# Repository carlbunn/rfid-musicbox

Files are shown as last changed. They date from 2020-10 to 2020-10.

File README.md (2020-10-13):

# rfid-musicbox

Create an easy way for your kids (or you!) to play music through your Sonos speakers by combining the excitement of RFID, ESP8266, Spotify & Sonos.

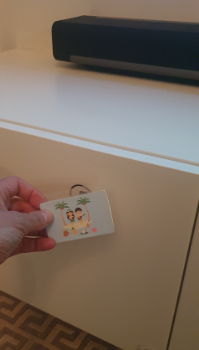
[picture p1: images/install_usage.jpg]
rfid-musicbox-install-usage
 

This project was built to predominantly allow my kids to play music, using simple RFID cards tapped against a reader to allow them to play the songs that they love without me being around.

1. [Repository File Structure](#repository-file-structure)
2. [Requirements](#requirements)
3. [ELectronics](#electronics)
4. [Software Build & Installation](#software-build--installation)
5. [Setup](#setup)
6. [Physical Installation](#physcial-installation)
7. [Usage](#usage)
8. [RFID Cards](#rfid-cards)
9. [References](#references)

## Repository File Structure
- /Fritzing - sketch of the wiring diagram
- /html - reference html of the pages served from the musicbox webserver
- /images - supporting images for documentation & build
- /src - source files for the project

## Requirements
This project should be extendable to additional music services, but was built to support playing Spotify songs through a network connected Sonos speaker. So at a minimum you will need:
1. Spotify Premium subscription
2. At least one Sonos speaker, connected to the same wifi network
3. 1 x NodeMCU ESP8266 board - I suggest the NodeMCU v3 Compatible ESP8266 CH340 Board, and make sure you check the version
4. 1 x MFRC-522 RFID reader board - you can sometimes pick up a kit for this that includes cables, and an RFID card
5. 7 x jumper wires to connect the MFRC-522 to the NodeMCU board
6. RFID cards - as many as you need, but at least one for testing. I bought a pack of 20 to start
7. 1 x Micro USB cable, and 1 USB Power Supply - I don't think the power requirements of the NodeMCU are that great, but your smartphone power supply will easily do

There are a few additional items I purchased for my particular set-up:
1. Something to put the assembled electronics in to. I used a simple plastic project box from a local electronics supplier.
2. A Micro USB 5Pin Male to Female w/Screw Hole Panel. I used this to put a female USB plug on the outside of the project box, and make it easier to unplug/move as needed.

## Electronics
To start with, you'll need to connect the electronics as shown below, or detailed in the [Fritzing wiring diagram](Fritzing/RFID-Musicbox.fzz).

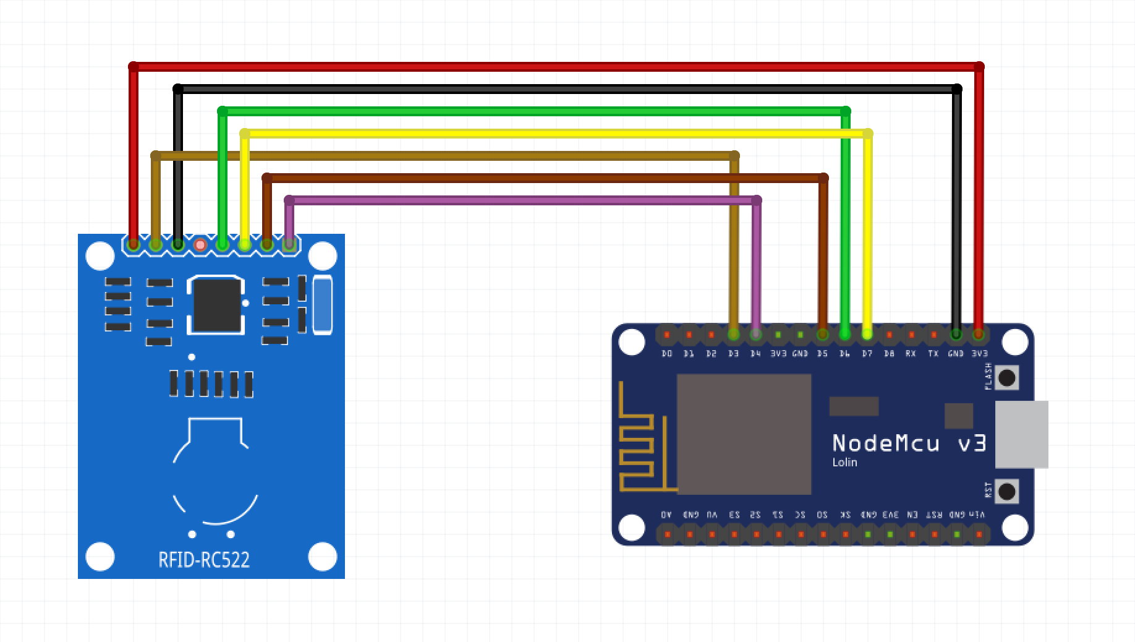
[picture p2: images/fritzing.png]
rfid-musicbox-Fritzing


Once connected, connect the Micro USB cable and power supply to the NodeMCU board.

## Software Build & Installation
The source code for this project was originally written uisng VS Code, and compiled using the [Platform IO](https://platformio.org/) plugin. If you'd prefer to use the Arduino IDE, a quick Google search should show you how to (relatively) easily adapt the source files to work as an .ino format.

*Note: Before you start the below steps, make sure your NodeMCU/ESP8266 board is connected to and powered by the USB port of your computer, not to the USB Power Supply.*

If you have already have VS Code installed:
1. Install [Platform IO IDE for VS Code](https://platformio.org/install/ide?install=vscode)
2. Add a new workspace using the **rfid-musicbox** folder
3. Build and upload the firmware using the IDE [this guide](https://docs.platformio.org/en/latest/integration/ide/vscode.html#ide-vscode) is helpful to get started

If you just want to install Platform IO to run on the command line:
1. Install [Platform IO Core](https://platformio.org/install/cli)
2. Open a command line prompt
3. Change to the **rfid-musicbox** folder
4. Run `platformio run --target upload`

By this point, you should have compiled the firmware and uploaded it to the NodeMCU.

## Setup
1. After the firmware is uploaded and installed, look for a new wifi hotspot named `musicbox_setup` using your phone or computer
2. Connect your device to the wifi hotspot, using the password `musicbox_setup`
3. The hotspot should automatically connect you using a captive portal style web page, otherwise just point your browser to the IP `http://192.168.4.1/`
4. Enter the details of/select your home Wifi network (along with network password) in the provided form, then click save
5. The rfid-musicbox should now try to connect to your home Wifi network
6. After a few seconds (/minutes) try to connect to `http://musicbox.local/` using your browser

*Note: If you use an Android phone to connect to the ESP8266, you might find you have trouble connecting due to inconsistent support for mDNS in Android phones. As a workaround, try connecting using the IP address of the device which you can find using your Router or using an app like [Fing](https://www.fing.com/products/fing-app)*

## Physcial Installation
I needed something that ensured the project box and electronics were all kept out of reach of my kids, and that they only had access to scan cards against a surface. Thankfully I had some Ikea cabinets installed under my TV that also happen to be directly underneath my loungeroom Sonos PLAYBAR.

The Ikea cabinets are standard [Besta cabinets](https://www.ikea.com/au/en/p/besta-tv-bench-with-doors-white-lappviken-white-s19299137/) with doors that are approximately 17mm thick, and the RFID signal has no problem passing through them.

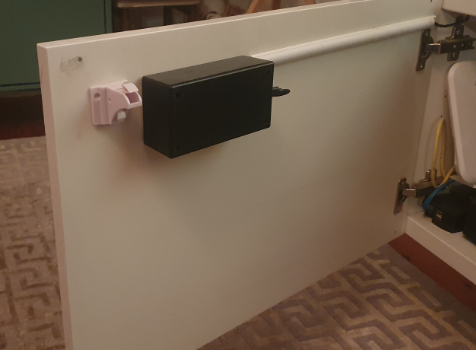
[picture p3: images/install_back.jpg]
rfid-musicbox-install-back
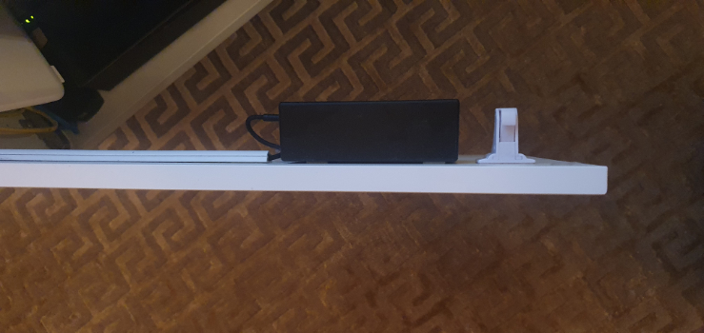
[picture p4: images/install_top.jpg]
rfid-musicbox-install-top
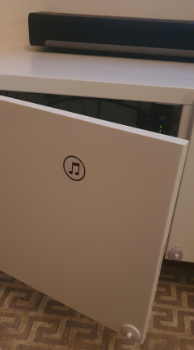
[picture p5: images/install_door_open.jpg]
rfid-musicbox-install-door-open
  

You can see from the images that I ended up running some simple trunking across the back of the door to house the USB power cable, and this runs to an extension within the cabinet.

I also printed out and stuck to the door a small music icon, just as a visual reference for the kids to know where to tap the RFID card. The icon was simply printed on A4, and stuck to the cabinet using [clear film](https://www.officeworks.com.au/shop/officeworks/p/studymate-self-adhesive-book-cover-roll-450mm-x-5m-clear-sm5450) (the kind you use to put over books to protect them)

## Usage
To start with, you'll need to assign a song to an RFID card. The URI information to access the song is stored on the RFID card, so you should be able to use one card to control multiple NodeMCUs with the same song.

To programme a card with a song:
1. Point your web browser to `http://musicbox.local/` (see the Note in [set-up](#setup) if you can't connect to this URL from your device)

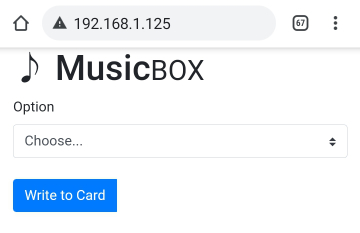
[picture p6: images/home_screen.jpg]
rfid-musicbox-home-screen


2. Select `Play Item` from the `Option` menu

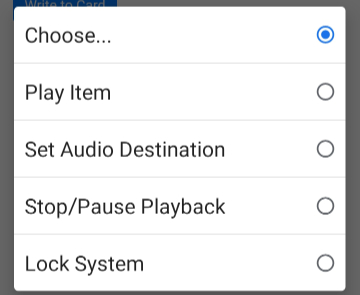
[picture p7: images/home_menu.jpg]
rfid-musicbox-home-menu


3. Click on the `Open Spotify Web Player` link to open a new browser page to the Spotify web player

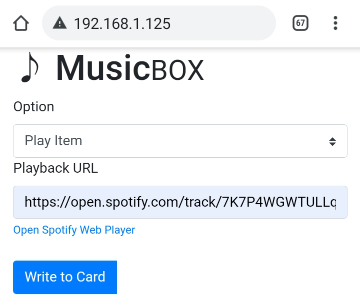
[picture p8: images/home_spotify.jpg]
rfid-musicbox-home-spotify


4. Search for the song you wish to write to the card in the Spotify web player
5. Hover over the selected song and click on the 3 dots rfid-musicbox-dots towards the right to open the menu
6. Select `Copy Song Link` to copy the link to the song to your clipboard

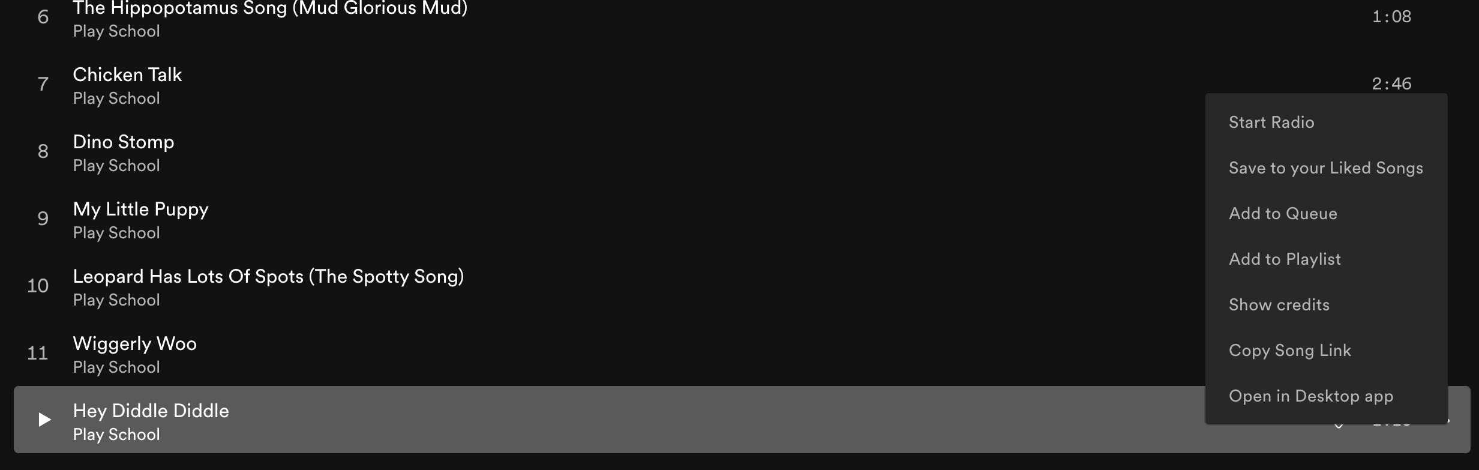
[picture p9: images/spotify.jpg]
rfid-musicbox-spotify


7. Close the window/navigate back to the browser page for the NodeMCU
8. Copy the song URL in to the `Playback URL` box
9. Click on `Write to Card`. You have 10 seconds to hold the RFID card you want to programme against the RFID reader/writer.

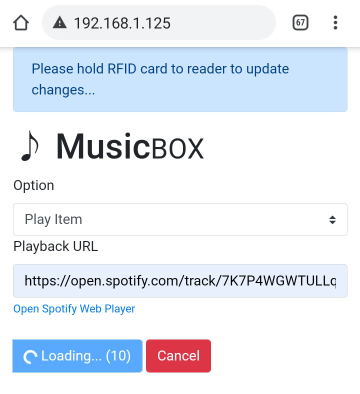
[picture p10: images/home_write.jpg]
rfid-musicbox-home-write


## RFID Cards
You can 'programme' an RFID card to start 1 of 4 different actions:
1. Play Item - play a song through the currently selected speaker
2. Set Audio Destination - change which Sonos speaker plays the next song
3. Stop/Pause Playback - pause/stop playback through the currently selected speaker
4. Lock System - lock and unlock the system from reading RFID cards (except a Lock card)
   - Note: 'locking' the system doesn't persist over reboots, so if the power is lost then the device will be unlocked again

All of this is done through the web interface.

To make the cards be easy to use for the kids, I used some colourful images sourced online that closely reflect the song title. These were printed out (using a standard printer), cut out, stuck to the cards using a spot of glue, and finally laminated to make them more durable. They work fantastically, and after a year are still looking like new.

I can't share the images I used, but I've included a [template file](images/card_template.afphoto) that you can use to size your images correctly for printing out.

## References
I used a lot of different references to build this project, and am thankful to a massive amount of online resources. Key resources I found extremely helpful included:
- https://lastminuteengineers.com/how-rfid-works-rc522-arduino-tutorial/ - a great reference on how RFID works, and how to combine it with an Arduino or equivalent device
- https://github.com/TheNitek/RfidShelf - awesome project, working to build an RFID mp3 player in to a shelf, which might be a good solution if you don't use Sonos or Spotify

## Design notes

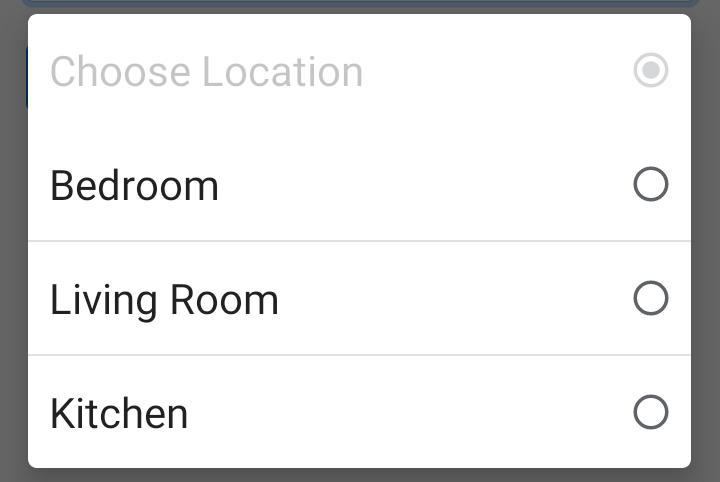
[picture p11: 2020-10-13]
images/home_location.jpg

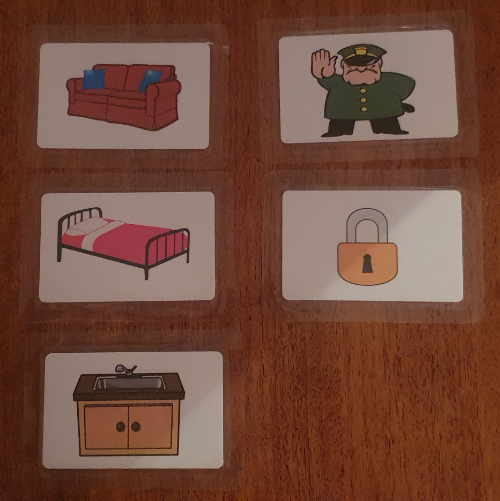
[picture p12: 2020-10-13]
images/cards_control.jpg

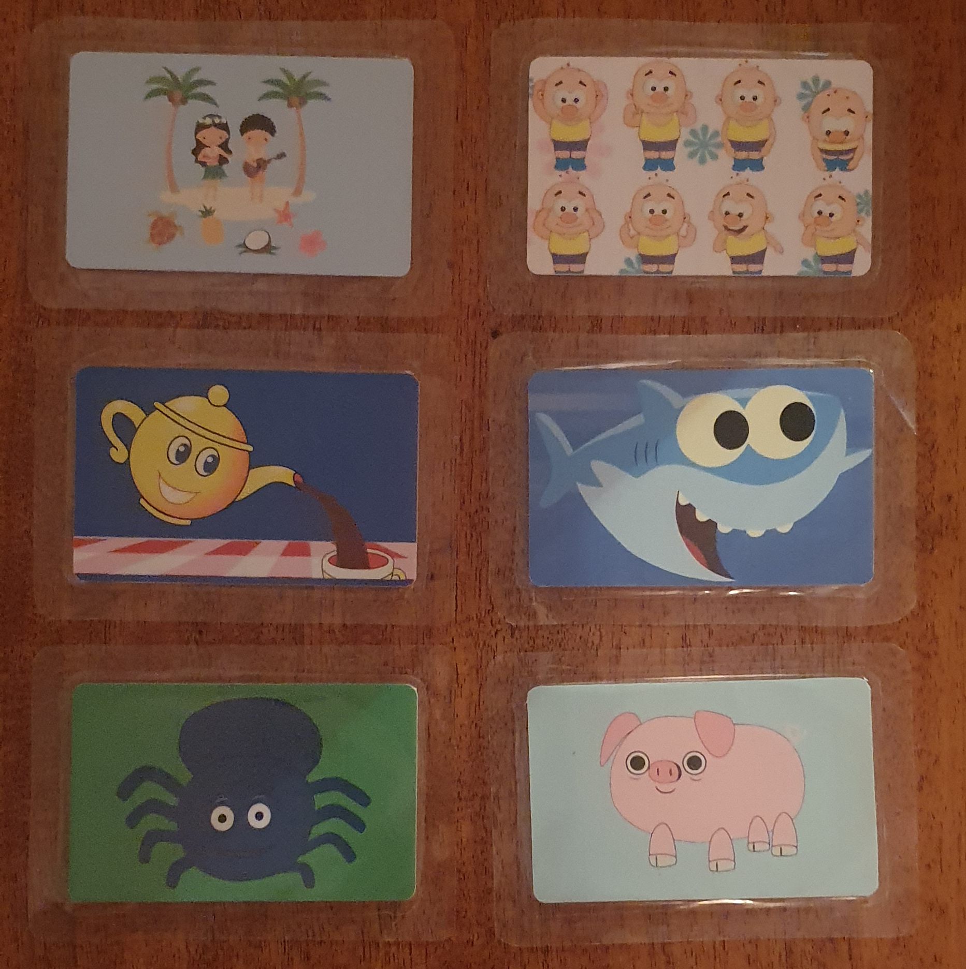
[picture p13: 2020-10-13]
images/cards_songs.jpg

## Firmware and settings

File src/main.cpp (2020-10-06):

#include <Arduino.h>
#include <WiFiManager.h>
#include "Config.h"
#include "Sonos.h"
#include "Rfid.h"
#include "WebServer.h"

#define MAIN_START_RFID
#define MAIN_START_SONOS
#define MAIN_START_WEB

// Defining instances to be used later
// in the setup and loop
Sonos g_sonos;
WiFiManager g_wifi_manager;
Rfid g_rfid_instance;
WebServer g_web_server;

// Using this as a bit of a hack to start/stop
// processing RFID requests
bool g_lock;

// We only support spotify at the moment, so
// we don't really store this value anywhere
// except here
const char* g_service_name = "spotify";
uint16_t g_service_id = 0;

// Currently using this to manage ongoing discovery
// of the sonos clients in the loop
unsigned long target_time = 0L;
const unsigned long DISCOVER_PERIOD = 2*60*1000UL; // 2 minutes

/**
 * Check and save any change of location
 *
 * Checks if the audio destination for playing has
 * changed, and if so it attempts to save that config
 * in the defined storage environment.
 */
void checkLocationChange()
{
    const SonosClient* client = g_sonos.getActiveClient();

    if (strcmp(CONFIG.stored_config.last_sonos_serial, client->serial_num) != 0)
    {
        memset(CONFIG.stored_config.last_sonos_serial, 0, sizeof(CONFIG.stored_config.last_sonos_serial));
        memcpy(CONFIG.stored_config.last_sonos_serial, client->serial_num, sizeof(client->serial_num));
        
        Serial.print(F("main::checkLocationChange saving Location change: "));Serial.println(CONFIG.stored_config.last_sonos_serial);

        // Write out the config to save it
        CONFIG.writeConfig();

        Serial.print(F("main::checkLocationChange Location change saved: "));Serial.println(CONFIG.stored_config.last_sonos_serial);
    }
}

/**
 * Process the callback from any RFID tag that's read
 *
 * Main callback passed to the RFID class, which in
 * turn processes the data provided that's read.
 */
void readRFIDCallback(const uint8_t* t_card_uid, const uint8_t* t_read_buffer, uint8_t t_buffer_size)
{
    // Just make sure that we have something to process
    if (!t_read_buffer)
    {
        Serial.print(F("main::readRFIDCallback no valid buffer provided/found"));
        return;
    }

    Serial.print(F("main::readRFIDCallback called ["));Serial.print((char*)t_read_buffer);Serial.println(F("]"));

    // Split the buffer up to the first space character
    // Commands should be one of:
    //   <COMMAND>
    //   <COMMAND> <ARGUMENT>
    char* command = strtok((char*)t_read_buffer, " ");
    
    if ((!g_lock) && strcmp(command, "PLAY") == 0)
    {
        // PLAY: expect next argument is a uri
        char* argument = strtok(NULL, " ");
        if (argument != NULL)
        {
            Serial.print(F("main::readRFIDCallback PLAY command ["));Serial.print(argument);Serial.println(F("]"));
            g_sonos.queueUri(g_service_id, argument);
            g_sonos.play();
        }
    }
    else if ((!g_lock) && strcmp(command, "LOCATION") == 0)
    {
        // LOCATION: expect next number is a Sonos Serial# for a location
        char* argument = strtok(NULL, " ");
        if (argument != NULL)
        {
            Serial.print(F("main::readRFIDCallback LOCATION command ["));Serial.print(argument);Serial.println(F("]"));
            g_sonos.setActiveClient(argument);

            // Check & save any change in the active client
            checkLocationChange();
        }
    }
    else if ((!g_lock) && strcmp(command, "STOP") == 0)
    {
        // STOP: no further arguments
        Serial.println(F("main::readRFIDCallback STOP command"));
        g_sonos.stop();
    }
    else if (strcmp(command, "LOCK") == 0)
    {
        // LOCK: no further arguments
        g_lock = !g_lock;
        Serial.print(F("main::readRFIDCallback LOCK command ["));Serial.print(g_lock ? F("LOCKED") : F("UNLOCKED"));Serial.println(F("]"));
    }
}

/**
 * Setup wifi access using Captive Portal
 *
 * Connects to a wifi network if details already
 * provided, otherwise it sets up a Captive Portal
 * for the user to enter ssid details.
 */
void setupWifi()
{
  // Setup wifi manager
  g_wifi_manager.setTimeout(CONFIG_WIFI_AP_TIMEOUT);
  
  if (!g_wifi_manager.autoConnect(CONFIG_WIFI_AP_NAME, CONFIG_WIFI_AP_PWD))
  {
    Serial.println(F("main::SetupWifi Failed to connect to WiFi and hit timeout"));
    
    // Reset and try again, or maybe put it to deep sleep
    ESP.reset();
    delay(1000);
  }
  
  Serial.print(F("main::SetupWifi connected, IP address: "));Serial.println(WiFi.localIP());
}

/**
 * Main setup function that configures elements
 * before we start the main loop.
 */
void setup()
{
    delay(100); // Seems to make flashing more reliable

    // Set up the serial port
    Serial.begin(CONFIG_SERIAL_SPEED);
    Serial.println();
    Serial.println(F("main::Setup starting..."));

    // Setup Wifi manager
    setupWifi();

    // Read the saved config
    CONFIG.begin();
    CONFIG.readConfig();

#ifdef MAIN_START_RFID
    // Prep the MFRC522 Card reader interface
    g_rfid_instance.begin();
#endif

#ifdef MAIN_START_SONOS
    // Discover Sonos players & set the active clients (based on config)
    g_sonos.begin();
    g_sonos.discover();

    g_service_id = g_sonos.getServiceID(g_service_name);

    // If there is a previously configured location
    // then set the location
    if (strcmp(CONFIG.stored_config.last_sonos_serial, "") != 0)
    {
        Serial.print(F("main::Setup using last Sonos Serial ["));Serial.print(CONFIG.stored_config.last_sonos_serial);Serial.println(F("]"));
        g_sonos.setActiveClient(CONFIG.stored_config.last_sonos_serial);
    }
#endif

#ifdef MAIN_START_WEB
    // Start the webserver
    g_web_server.begin(CONFIG_WEB_PORT, CONFIG_WEB_NAME, &g_rfid_instance, &g_sonos);
#endif

    // Start unlocked, but should probably read this from
    // a config so we don't use a power reset to unlock the device
    g_lock = false;

    Serial.println(F("main::Setup ...completed"));
}

/**
 * Main loop function
 */
void loop()
{
#ifdef MAIN_START_RFID
    // Check if we need to handle any RFID events
    uint8_t buffer[255];
    g_rfid_instance.handle(readRFIDCallback, buffer, sizeof(buffer));
#endif

#ifdef MAIN_START_WEB
    // Check for any Web requests
    g_web_server.handle();
#endif

#ifdef MAIN_START_SONOS
    // Check if there has been a change to the Active location
    // that we need to store for next time. This should really
    // never trigger as we also catch it in the RFID location
    // change area of the callback, but is here just in case
    checkLocationChange();

    // Run discovery of new Sonos clients every period
    if ((millis() - target_time) >= DISCOVER_PERIOD)
    {
        Serial.println(F("main::Loop running discovery for clients"));
        target_time += DISCOVER_PERIOD;
        g_sonos.discover();
    }
#endif
}

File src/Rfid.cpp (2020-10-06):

#include "Rfid.h"
#include <SPI.h>

/**
 * Good reference document on how RFID works
 * https://lastminuteengineers.com/how-rfid-works-rc522-arduino-tutorial/
*/

void Rfid::begin()
{
    SPI.begin();          // Init SPI bus
    m_mfrc522.PCD_Init(); // Init MFRC522 card
    delay(4);             // Add a short delay to allow hardware initialisation

    m_mfrc522.PCD_DumpVersionToSerial();

    // Prepare the key (used both as key A and as key B)
    // using FFFFFFFFFFFFh which is the default at chip delivery from the factory
    memset(m_key.keyByte, 0xFF, MFRC522::MF_KEY_SIZE);

    DEBUG_RFID(Serial.print(F("Rfid::begin Using key (for A and B): "));
                printByteArray(m_key.keyByte, MFRC522::MF_KEY_SIZE);
                Serial.println());
}

void Rfid::writeRfid(const uint8_t* t_write_buffer, uint16_t t_write_buffer_size)
{
    // Set ourselves up for the write
    m_write_on_next_card = true;
    m_write_timer = millis();
    
    // Copy the write buffer over to a new buffer
    
    // TODO: Maybe we should just allocate a large char array to buffer this instead
    if (m_write_buffer) free(m_write_buffer); // Free any previous memory allocated to the pointer

    m_write_buffer = (uint8_t*)malloc(t_write_buffer_size * sizeof(uint8_t));
    memcpy(m_write_buffer, t_write_buffer, t_write_buffer_size * sizeof(uint8_t));
    m_write_buffer_size = t_write_buffer_size;
}

void Rfid::setWriteTimeout(const uint32_t t_length)
{
    DEBUG_RFID(Serial.print(F("Rfid::setWriteTimeout Setting timeout to ["));
                Serial.print(t_length);
                Serial.println(F("]")));

    m_write_timeout = t_length;
}

void Rfid::cancelWriteRfid()
{
    DEBUG_RFID(Serial.println(F("Rfid::cancelWriteRfid Cancelling write")));
    
    m_write_on_next_card = false;
    if (m_write_buffer) free(m_write_buffer);
    m_write_buffer = nullptr;
    m_write_buffer_size = 0;
}

void Rfid::handle(void (*read_callback)(const uint8_t*, const uint8_t*, const uint8_t), uint8_t* t_read_buffer, uint16_t t_buffer_size)
{
    // Check whether the write timer has expired 
    if (m_write_on_next_card && (millis() > (m_write_timeout + m_write_timer)))
    {
        Serial.println(F("Rfid::handleRfid Write timer expired. Cancelling write to card"));

        cancelWriteRfid(); // Clear everything out
    }

    // Check whether a card has been presented

    //TODO: improve the new card detection routine as per researched code
    // Reset the loop if no new card present on the sensor/reader. This saves the entire process when idle.
    if (!m_mfrc522.PICC_IsNewCardPresent())
        return;

    // Select one of the cards
    if (!m_mfrc522.PICC_ReadCardSerial())
        return;

    Serial.println(F("Rfid::handleRfid New card detected"));

    MFRC522::PICC_Type piccType = m_mfrc522.PICC_GetType(m_mfrc522.uid.sak);

    // Show some details of the PICC (that is: the tag/card)
    DEBUG_RFID(Serial.print(F("Card UID: "));
                printByteArray(m_mfrc522.uid.uidByte, m_mfrc522.uid.size);
                Serial.println();
                Serial.print(F("PICC type: "));
                Serial.println(m_mfrc522.PICC_GetTypeName(piccType)));

    // Check for compatibility
    if (
            piccType != MFRC522::PICC_TYPE_MIFARE_MINI
        &&  piccType != MFRC522::PICC_TYPE_MIFARE_1K
        &&  piccType != MFRC522::PICC_TYPE_MIFARE_4K)
    {
        Serial.println(F("Rfid::handleRfid This app only works with MIFARE Classic cards."));
        return;
    }

    if (m_write_on_next_card)
    {
        DEBUG_RFID(Serial.println(F("Rfid::handleRfid Writing to a card...")));

        writeBufferToCard(RFID_START_SECTOR, m_write_buffer, m_write_buffer_size);
        
        cancelWriteRfid(); // Clear everything out
    }
    else
    {
        DEBUG_RFID(Serial.println(F("Rfid::handleRfid Reading from a card...")));

        readBufferFromCard(RFID_START_SECTOR, t_read_buffer, t_buffer_size);
        
        read_callback(m_mfrc522.uid.uidByte, t_read_buffer, t_buffer_size);
    }

    // Halt PICC
    m_mfrc522.PICC_HaltA();
    // Stop encryption on PCD
    m_mfrc522.PCD_StopCrypto1();

    DEBUG_RFID(Serial.println(F("Rfid::handleRfid Completed")));
}

Rfid::RfidIfaceReturn Rfid::writeBufferToCard(uint8_t t_starting_sector, const uint8_t* t_buffer, uint16_t t_buffer_size)
{
    Rfid::RfidIfaceReturn ret_val = RfidIfaceReturn::OK;

    DEBUG_RFID(Serial.println(F("Rfid::writeBufferToCard Writing string to a card")));

    for (auto i = 0; i <= ceil(t_buffer_size / RFID_BLOCK_SIZE); i++)
    {
        uint8_t block_content[RFID_BLOCK_SIZE];
        uint8_t block_size = (t_buffer_size < ((i + 1) * RFID_BLOCK_SIZE)) ? (t_buffer_size - (i * RFID_BLOCK_SIZE)) : RFID_BLOCK_SIZE;

        memset(block_content, 0, RFID_BLOCK_SIZE);
        memcpy(block_content, &t_buffer[i * RFID_BLOCK_SIZE], block_size);

        DEBUG_RFID(Serial.print(F("Rfid::writeBufferToCard Writing sector["));
                    Serial.print(t_starting_sector + (uint8_t)(i / 3));
                    Serial.print(F("] block["));
                    Serial.print(i % 3);
                    Serial.print(F("] ["));
                    printByteArray(block_content, block_size);
                    Serial.println(F("]")));
        
        if (writeRfidBlock(t_starting_sector + (uint8_t)(i / 3), i % 3, block_content, sizeof(block_content)) == RfidIfaceReturn::OK)
        {
            DEBUG_RFID(Serial.println(F("Rfid::writeBufferToCard Written buffer to a card")));
        }
        else
        {
            DEBUG_RFID(Serial.println(F("Rfid::writeBufferToCard Error while writing a card")));
        }
    }
    return ret_val;
}
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

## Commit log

2020-10-07 Added Fritzing
    [RFID-Musicbox.fzz]
2020-10-07 Added supporting images
    [RFID-Musicbox.fzz]
